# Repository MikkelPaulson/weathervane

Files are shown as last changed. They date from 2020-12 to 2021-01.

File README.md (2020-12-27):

# Weathervane

A display that will live next to my front door and display the current weather
conditions. Components:

* [Raspberry Pi Zero W](https://www.raspberrypi.org/products/raspberry-pi-zero-w/)
* [Waveshare 3.7" e-Paper HAT](https://www.waveshare.com/3.7inch-e-paper-hat.htm)

As part of this project, I'm also working on a Rust interface for the Waveshare
display, which I'll spin off into a separate crate when it's done.

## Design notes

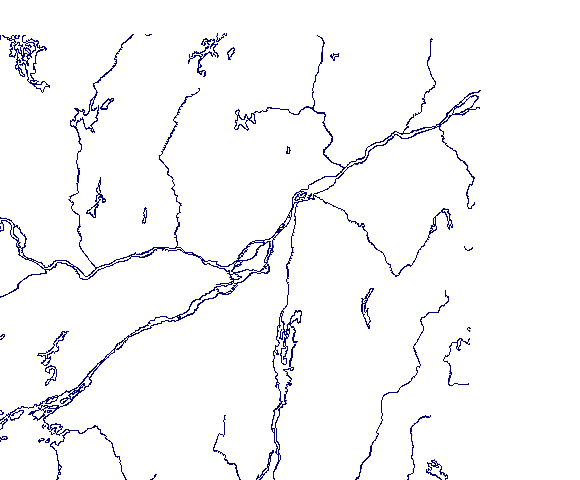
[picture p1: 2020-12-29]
images/radar-rivers.gif

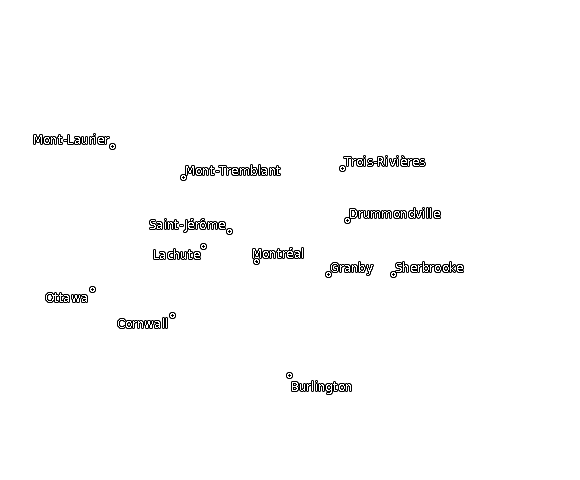
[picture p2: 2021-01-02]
images/radar-towns.gif

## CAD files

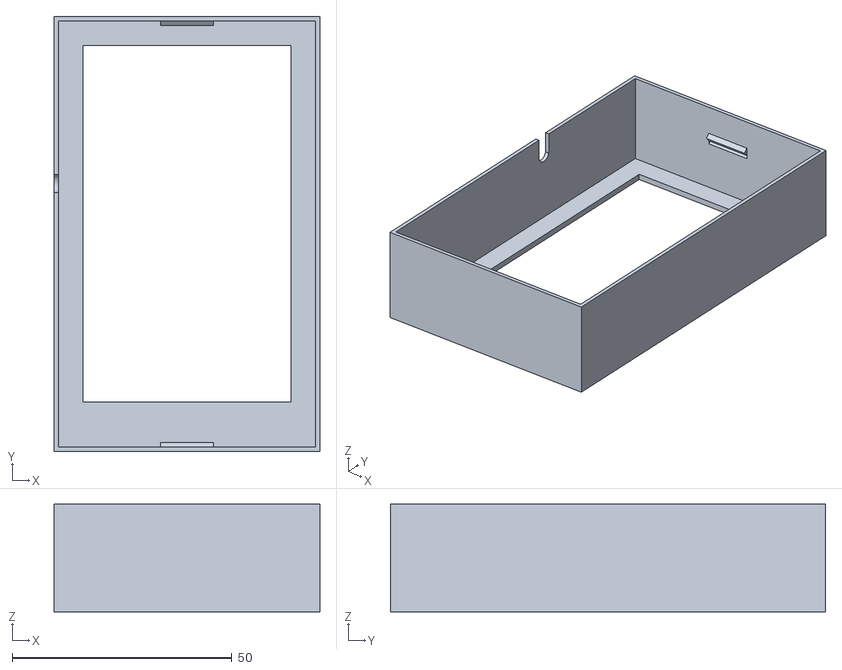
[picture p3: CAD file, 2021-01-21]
case/front.stl
60.5 x 99.0 x 24.5

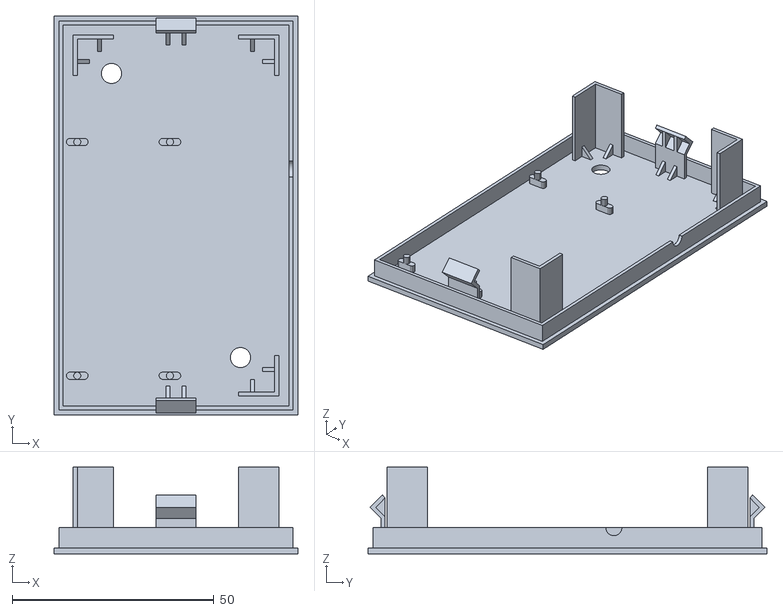
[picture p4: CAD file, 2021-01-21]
case/back.stl
60.5 x 99.0 x 21.5

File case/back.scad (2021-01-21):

include<./variables.scad>

bottom_inside_width = hat_width - wall_thickness * 2;
bottom_inside_length = hat_length - wall_thickness * 2;

color("gray")
base();

translate([
    wall_thickness * 2 + wall_buffer,
    wall_thickness * 2 + wall_buffer,
    back_thickness
]) {
    color("blue")
    translate([0, 4, 0])
    pins();
    
    color("red")
    supports();
    
    color("green")
    clips();
}

module base() {
    screw_hole_radius = 2.5;
    screw_hole_inset = 12;
    
    difference() {
        cube([
            case_width,
            case_length,
            back_thickness
        ]);
        
        translate([
            wall_thickness * 2 + wall_buffer + screw_hole_inset,
            hat_length + wall_buffer - screw_hole_inset,
            0
        ])
        cylinder(
            h = 30,
            r = screw_hole_radius,
            center = true
        );
        
        translate([
            hat_width + wall_buffer - screw_hole_inset,
            wall_thickness * 2 + wall_buffer + screw_hole_inset,
            0
        ])
        cylinder(
            h = 30,
            r = screw_hole_radius,
            center = true
        );
    };

    translate([
        wall_thickness + wall_buffer,
        wall_thickness + wall_buffer,
        back_thickness
    ])
    difference() {
        cube([
            hat_width,
            hat_length,
            5
        ]);
        
        translate([wall_thickness, wall_thickness, -2])
        cube([
            bottom_inside_width,
            bottom_inside_length,
            10
        ]);
        
        translate([
            hat_width - 1,
            cable_cutout_offset - wall_thickness - wall_buffer,
            cable_cutout_height - back_thickness
        ])
        rotate([0, 90, 0])
        cylinder(
            h = wall_thickness + 2,
            r = cable_cutout_radius,
            center = true
        );
    };
}

module pins() {
    pi_length = 65;
    pi_width = 30;
    pin_inset = 3.5;
    
    translate([
        pin_inset,
        pin_inset,
        0
    ])
    pin();
    
    translate([
        pi_width - pin_inset,
        pin_inset,
        0
    ])
    pin();
    
    translate([
        pi_width - pin_inset,
        pi_length - pin_inset,
        0
    ])
    pin();
    
    translate([
        pin_inset,
        pi_length - pin_inset,
        0
    ])
    pin();
    
    module pin() {
        pin_height = hat_bottom_padding + 2;
        pin_radius = 0.9;
        
        rotate([0, 0, 90])
        union() {
            cylinder(
                h = pin_height,
                r = pin_radius
            );
            
            translate([
                -pin_radius,
                -pin_radius * 2,
                0
            ])
            cube([
                pin_radius * 2,
                pin_radius * 4,
                hat_bottom_padding
            ]);
            
            translate([
                0,
                -pin_radius * 2,
                0
            ])
            cylinder(
                h = hat_bottom_padding,
                r = pin_radius
            );
            
            translate([
                0,
                pin_radius * 2,
                0
            ])
            cylinder(
                h = hat_bottom_padding,
                r = pin_radius
            );
        }
    }
}

module supports() {
    support_inset = 2.5;
    
    translate([
        hat_width - wall_thickness * 2 - support_inset,
        support_inset,
        0
    ])
    support();
    
    translate([
        hat_width - wall_thickness * 2 - support_inset,
        hat_length - wall_thickness * 2 - support_inset,
        0
    ])
    mirror([0, 1, 0])
    support();
    
    translate([
        support_inset,
        hat_length - wall_thickness * 2 - support_inset,
        0
    ])
    mirror([-1, 1, 0])
    support();
    
    module support() {
        support_height = hat_height + hat_bottom_padding - hat_thickness;
        support_width = 10;
        support_thickness = wall_thickness;
        
        fillet_thickness = support_thickness;
        fillet_inset = 3;
        
        linear_extrude(height = support_height)
        polygon([
            [0, 0],
            [-support_width, 0],
            [-support_width, support_thickness],
            [-support_thickness, support_thickness],
            [-support_thickness, support_width],
            [0, support_width]
        ]);
        
        translate([-(support_width - fillet_thickness - fillet_inset), support_thickness, 0])
        rotate([0, -90, 0])
        support_fillet();
        
        translate([-support_thickness, support_width - fillet_inset, 0])
        rotate([0, -90, 90])
        support_fillet();
        
        module support_fillet() {
            fillet_size = 3;
            
            linear_extrude(height = fillet_thickness)
            polygon([
                [0, 0],
                [fillet_size, 0],
                [0, fillet_size],
            ]);
        }
    }
}
module clips() {
    clip_inset = 1;
    clip_point_depth = clip_inset + wall_thickness * 1.5 + wall_buffer;
    
    translate([
        bottom_inside_width / 2,
        clip_inset,
        0
    ])
    clip();
    
    translate([
        bottom_inside_width / 2,
        bottom_inside_length - clip_inset,
        0
    ])
    rotate([0, 0, 180])
    clip();
    
    module clip() {
        clip_thickness = wall_thickness;
        
        fillet_thickness = clip_thickness;
        fillet_inset = 2;
        
        rotate([0, -90, 0])
        linear_extrude(height = clip_width, center = true)
        polygon([
            [0, 0],
        
            [clip_point_height - clip_point_depth, 0],
            [clip_point_height, -clip_point_depth],
            [clip_point_height + clip_point_depth + clip_thickness / sqrt(2) / 2, clip_thickness / sqrt(2) / 2],
        
            [clip_point_height + clip_point_depth - clip_thickness / sqrt(2) / 2, clip_thickness],
            [clip_point_height, -(clip_point_depth - (clip_thickness * sqrt(2)))],
            [clip_point_height - clip_point_depth + clip_thickness / sqrt(2) / 2, clip_thickness],
            [0, clip_thickness],
        ]);
        
        translate([clip_width / 2 - fillet_thickness - fillet_inset, 0, 0])
        clip_fillet();
        
        translate([
            -(clip_width / 2 - fillet_thickness - fillet_inset),
            0,
            0
        ])
        clip_fillet();
        
        module clip_fillet() {
            fillet_size = 3;
            
            rotate([0, -90, 0])
            linear_extrude(height = fillet_thickness, center = true)
            union() {
                polygon([
                
                    [clip_point_height + clip_point_depth - clip_thickness / sqrt(2) / 2, clip_thickness],
                    [clip_point_height, -(clip_point_depth - (clip_thickness * sqrt(2)))],
                    [clip_point_height - clip_point_depth + clip_thickness / sqrt(2) / 2, clip_thickness]
                ]);
                
                polygon([
                    [0, clip_thickness],
                    [fillet_size, clip_thickness],
                    [0, fillet_size + clip_thickness],
                ]);
            }
        }
    }
}
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

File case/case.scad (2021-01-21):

include<./back.scad>

translate([100, 0, 0])
front();

$vpt = [(100 + hat_width) / 2, hat_length / 2, 0];

module front() {
    include<./front.scad>
}

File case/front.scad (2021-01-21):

include<./variables.scad>

top_inside_width = case_width - wall_thickness * 2;
top_inside_length = case_length - wall_thickness * 2;

clip_point_height_rev = case_height - back_thickness - clip_point_height;

cable_cutout_height_rev = case_height - cable_cutout_height;

color("gray")

union() {
    difference() {
        base();
        
        // Clips inset
        translate([case_width / 2, 0, 0])
        rotate([0, -90, 0])
        linear_extrude(
            height = clip_width + 2,
            center = true
        )
        polygon([
            [clip_point_height_rev + wall_thickness, wall_thickness * 1.5],
            [clip_point_height_rev, wall_thickness / 2],
            [clip_point_height_rev - wall_thickness, wall_thickness * 1.5],
        ]);
        
        translate([case_width / 2, case_length, 0])
        rotate([180, -90, 0])
        linear_extrude(
            height = clip_width + 2,
            center = true
        )
        polygon([
            [clip_point_height_rev + wall_thickness, wall_thickness * 1.5],
            [clip_point_height_rev, wall_thickness / 2],
            [clip_point_height_rev - wall_thickness, wall_thickness * 1.5],
        ]);
    }
    
    // Clips
    translate([case_width / 2, 0, 0])
    rotate([0, -90, 0])
    linear_extrude(
        height = clip_width + 2,
        center = true
    )
    polygon([
        [clip_point_height_rev, wall_thickness / 2],
        [clip_point_height_rev + wall_thickness * 1.5, wall_thickness * 2],
        [clip_point_height_rev + wall_thickness * 3, wall_thickness / 2],
    ]);
    
    translate([case_width / 2, case_length, 0])
    rotate([180, -90, 0])
    linear_extrude(
        height = clip_width + 2,
        center = true
    )
    polygon([
        [clip_point_height_rev, wall_thickness / 2],
        [clip_point_height_rev + wall_thickness * 1.5, wall_thickness * 2],
        [clip_point_height_rev + wall_thickness * 3, wall_thickness / 2],
    ]);
}

module base() {
    // Bottom face
    difference() {
        cube([
            case_width,
            case_length,
            back_thickness
        ]);
        
        translate([
            display_inset + wall_thickness + wall_buffer,
            case_length - (display_inset + wall_thickness + wall_buffer + display_length),
            -1
        ])
        cube([
            display_width,
            display_length,
            back_thickness + 2
        ]);
    }
    
    // Sides
    difference() {
        cube([
            case_width,
            case_length,
            case_height - back_thickness
        ]);
        
        translate([
            wall_thickness,
            wall_thickness,
            -1
        ])
        cube([
            top_inside_width,
            top_inside_length,
            case_height - back_thickness + 2
        ]);
        
        // Cable cutout
        translate([
            -1,
            cable_cutout_offset,
            0
        ])
        rotate([0, 90, 0])
        linear_extrude(
            height = wall_thickness + 2
        )
        union() {
            translate([
                -cable_cutout_height_rev,
                0
            ])
            circle(
                r = cable_cutout_radius
            );
            
            translate([
                -(case_height - back_thickness + 1),
                -cable_cutout_radius
            ])
            square([
                cable_cutout_height,
                cable_cutout_radius * 2
            ]);
        }
    }
}

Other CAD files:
case/variables.scad

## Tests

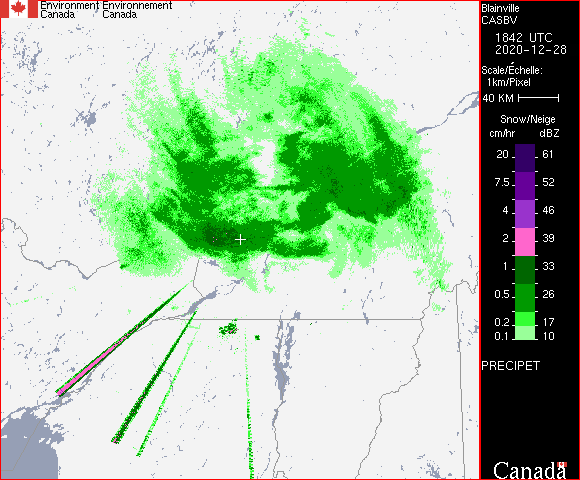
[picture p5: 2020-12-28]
images/radar-test.gif

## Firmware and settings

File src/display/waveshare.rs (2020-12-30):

use super::Display;
use rppal::{gpio, spi};

pub use epaper3_7in::EPaper3_7in;

mod epaper3_7in {
    use super::{Display, GpioInputPin, GpioOutputPin, SpiHardwareInterface};

    use rppal::{gpio, spi};

    use std::thread;
    use std::time::Duration;

    pub struct EPaper3_7in {
        hardware_interface: Box<dyn SpiHardwareInterface>,
    }

    impl EPaper3_7in {
        const PIN_DC: u8 = 25; // Data/command pin (high = data, low = command)
        const PIN_RST: u8 = 17; // External reset pin (low = reset)
        const PIN_BUSY: u8 = 24; // Busy output pin (low = busy)

        pub const DISPLAY_WIDTH: usize = 280;
        pub const DISPLAY_HEIGHT: usize = 480;

        pub fn new() -> Self {
            let gpio = gpio::Gpio::new().expect("Unable to connect to GPIO.");

            Self {
                hardware_interface: Box::new(HardwareInterface {
                    spi: spi::Spi::new(
                        spi::Bus::Spi0,
                        spi::SlaveSelect::Ss0,
                        10_000_000, // 10 MHz = 100 ns
                        spi::Mode::Mode0,
                    )
                    .expect("Unable to initialize SPI connection."),
                    pin_dc: gpio
                        .get(Self::PIN_DC)
                        .expect("Unable to acquire data/command pin.")
                        .into_output(),
                    pin_rst: gpio
                        .get(Self::PIN_RST)
                        .expect("Unable to acquire reset pin.")
                        .into_output(),
                    pin_busy: gpio
                        .get(Self::PIN_BUSY)
                        .expect("Unable to acquire busy pin.")
                        .into_input(),
                }),
            }
        }

        fn clear(&mut self) -> Result<(), &'static str> {
            self.draw_raw(
                &[0xFF].repeat(Self::DISPLAY_WIDTH / 8 * Self::DISPLAY_HEIGHT),
                &[0xFF].repeat(Self::DISPLAY_WIDTH / 8 * Self::DISPLAY_HEIGHT),
            )
        }

        fn reset(&mut self) {
            self.hardware_interface
                .set_level(GpioOutputPin::Reset, gpio::Level::High);
            thread::sleep(Duration::from_millis(30));
            self.hardware_interface
                .set_level(GpioOutputPin::Reset, gpio::Level::Low);
            thread::sleep(Duration::from_millis(3));
            self.hardware_interface
                .set_level(GpioOutputPin::Reset, gpio::Level::High);
            thread::sleep(Duration::from_millis(30));
        }

        fn load_look_up_table(&mut self) -> Result<(), &'static str> {
            self.run(Command::WriteLookUpTableRegister(&[
                0x2A, 0x06, 0x15, 0x00, 0x00, 0x00, 0x00, 0x00, 0x00, 0x00, //1
                0x28, 0x06, 0x14, 0x00, 0x00, 0x00, 0x00, 0x00, 0x00, 0x00, //2
                0x20, 0x06, 0x10, 0x00, 0x00, 0x00, 0x00, 0x00, 0x00, 0x00, //3
                0x14, 0x06, 0x28, 0x00, 0x00, 0x00, 0x00, 0x00, 0x00, 0x00, //4
                0x00, 0x00, 0x00, 0x00, 0x00, 0x00, 0x00, 0x00, 0x00, 0x00, //5
                0x00, 0x02, 0x02, 0x0A, 0x00, 0x00, 0x00, 0x08, 0x08, 0x02, //6
                0x00, 0x02, 0x02, 0x0A, 0x00, 0x00, 0x00, 0x00, 0x00, 0x00, //7
                0x00, 0x00, 0x00, 0x00, 0x00, 0x00, 0x00, 0x00, 0x00, 0x00, //8
                0x00, 0x00, 0x00, 0x00, 0x00, 0x00, 0x00, 0x00, 0x00, 0x00, //9
                0x00, 0x00, 0x00, 0x00, 0x00, 0x00, 0x00, 0x00, 0x00, 0x00, //10
                0x22, 0x22, 0x22, 0x22, 0x22,
            ]))
        }

        fn run(&mut self, command: Command) -> Result<(), &'static str> {
            let (command_byte, data_bytes) = command.get_bytes();

            self.hardware_interface
                .set_level(GpioOutputPin::DataCommand, gpio::Level::Low);
            self.hardware_interface
                .write_to_spi(&[command_byte])
                .map_err(|_| "Unable to write command.")?;

            if !data_bytes.is_empty() {
                self.hardware_interface
                    .set_level(GpioOutputPin::DataCommand, gpio::Level::High);
                for chunk in data_bytes[..].chunks(4096) {
                    self.hardware_interface
                        .write_to_spi(&chunk)
                        .map_err(|_| "Unable to write data.")?;
                }
            }

            if command.is_blocking()
                && self.hardware_interface.get_level(GpioInputPin::Busy) == gpio::Level::High
            {
                print!("Waiting for device...");
                while self.hardware_interface.get_level(GpioInputPin::Busy) == gpio::Level::High {
                    thread::sleep(Duration::from_millis(200));
                }
                println!("Done");
            }

            Ok(())
        }

        fn draw_raw(&mut self, register1: &[u8], register2: &[u8]) -> Result<(), &'static str> {
            self.run(Command::Unknown0x49)?;

            self.run(Command::Unknown0x4E)?;
            self.run(Command::Unknown0x4F)?;
            self.run(Command::WriteRegister1(&register1))?;

            self.run(Command::Unknown0x4E)?;
            self.run(Command::Unknown0x4F)?;
            self.run(Command::WriteRegister2(&register2))?;

            self.load_look_up_table()?;

            self.run(Command::UpdateSequence(&[0xCF]))?;
            self.run(Command::Display)?;

            Ok(())
        }
    }

    impl Display for EPaper3_7in {
        type Err = &'static str;

        fn on(&mut self) -> Result<(), &'static str> {
            self.reset();

            self.run(Command::Unknown0x12)?;
            thread::sleep(Duration::from_millis(300));

            self.run(Command::Unknown0x46)?;
            self.run(Command::Unknown0x47)?;

            self.run(Command::SetGateNumber)?;

            self.run(Command::SetGateVoltage)?;

            self.run(Command::SetSourceVoltage)?;

            self.run(Command::SetDataEntrySequence)?;
            self.run(Command::SetBorder)?;
            self.run(Command::SetBoosterStrength)?;
            self.run(Command::SetInternalSensorOn)?;
            self.run(Command::SetVComValue)?;
            self.run(Command::SetDisplayOption(&[
                0x00, 0x00, 0x00, 0x00, 0x00, 0x00, 0x00, 0x00, 0x00, 0x00,
            ]))?;

            self.run(Command::SetXRamPosition(&[0x00, 0x00, 0x17, 0x01]))?;
            self.run(Command::SetYRamPosition(&[0x00, 0x00, 0xDF, 0x01]))?;

            self.run(Command::UpdateSequence(&[0xCF]))?;

            Ok(())
        }

        fn off(&mut self) -> Result<(), &'static str> {
            self.clear()?;
            self.sleep()?;

            Ok(())
        }

        fn sleep(&mut self) -> Result<(), &'static str> {
            self.run(Command::Unknown0x50)?;
            self.run(Command::PowerOff)?;
            self.run(Command::Sleep)?;
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

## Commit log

2020-12-26 swap busy pin behaviour
2020-12-28 trying again to draw piet samples
2020-12-28 fix rendering non-alpha channel
    [display.rs]
2020-12-30 calculate current conditions from parent position
2021-01-21 rotate image and tweak output
    * output image upside down (since it's mounted upside down)
    * add a bit of padding around the edges, reducing the number of events
    in the (2-)hourly forecast to 5 from 6
    * flip the radar and temperature daily to mitigate burn-in
2021-01-21 add FreeSCAD and STL files for the case
    [back.scad, back.stl, case.scad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]
